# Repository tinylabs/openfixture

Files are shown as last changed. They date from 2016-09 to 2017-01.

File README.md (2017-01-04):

# OpenFixture





## Goal
The motivation of OpenFixture was to make a parametric fixturing system that could take fully generated inputs from kicad and produce a test fixture with minimal effort. The easiest way to use it is through the kicad python scripting interface.

## Parameters
For most projects (if using the standard BOM) the only parameters you'll need to set are mat_th and pcb_th. Something like the following should be sufficient:
```
./GenFixture.py --board [path to board.kicad_pcb] --mat_th [thickness in mm] --pcb_th [thickness in mm] --out board-fixture

usage: GenFixture.py [-h] --board BOARD --mat_th MAT_TH --out OUT
                     [--pcb_th PCB_TH] [--screw_len SCREW_LEN]
                     [--screw_d SCREW_D] [--layer LAYER] [--flayer FLAYER]
                     [--ilayer ILAYER]

optional arguments:
  -h, --help            show this help message and exit
  --board BOARD         <board_name.kicad_pcb>
  --mat_th MAT_TH       material thickness (mm)
  --out OUT             output directory
  --pcb_th PCB_TH       pcb thickness (mm)
  --screw_len SCREW_LEN  Assembly screw thread length (default = 14mm)
  --screw_d SCREW_D     Assembly screw diameter (default=M3)
  --layer LAYER         F.Cu | B.Cu
  --flayer FLAYER       Eco1.User | Eco2.User
  --ilayer ILAYER       Eco1.User | Eco2.User
```					    
The resulting output is:
  * A 3D model of the test fixture for visualization
  * A 2D DXF that can be directly lasercut for assembly

## Recommended workflow for kicad
  1. Clone this repo if you haven't already
  2. Setup a project specific bash script (use genfixture.sh as an example)
  3. Enter board specific info, fixture hardware, material thickness, etc.
  4. Whenever the layout changes call ./genfixture.sh (from repo) and pass path to .kicad_pcb file.
  5. Fixture will be generated in $OUTPUT folder.
  6. If anyone is interested in integrating this into kicad directly I'd be happy to support it and clean it up...
  
## Hardware
  * All that is needed is M3 (14mm+) screws, M3 hex nuts, and lasercut parts
  * I use nylon bushings in the main pivot with m3 screws for a smoother joint but this is optional 

## Documentation
http://tinylabs.io/openfixture

## BOM
http://tinylabs.io/openfixture-bom

## Kicad export
http://tinylabs.io/openfixture-kicad-export

## Assembly
More info including detailed assembly instructions at http://tinylabs.io/openfixture-assembly

## Dependencies
  * Newer version of openscad >= 2015.03-1
  * kicad or other EDA software. Please email me if you have instructions for other packages so I can add them.

## Known Issues
  * When loading the fonts file a new small window opens in Ubuntu. Seems innocuous but still annoying [Only seen on ubuntu 14.04]

## License
Creative Commons (CC BY-SA 4.0)

## Contributors
  * Elliot Buller - Tiny Labs Inc

Please email with any pull requests or new feature requests
elliot@tinylabs.io

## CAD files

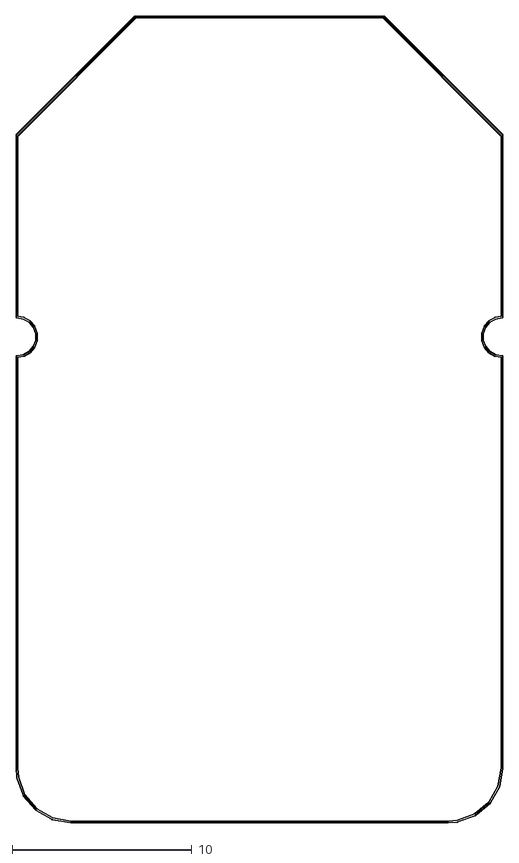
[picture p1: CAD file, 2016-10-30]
rfid_fob-outline.dxf
27.1 x 44.9

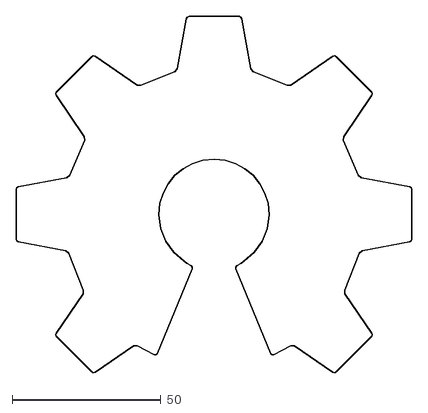
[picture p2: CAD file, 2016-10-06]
osh_logo.dxf
132.9 x 119.6

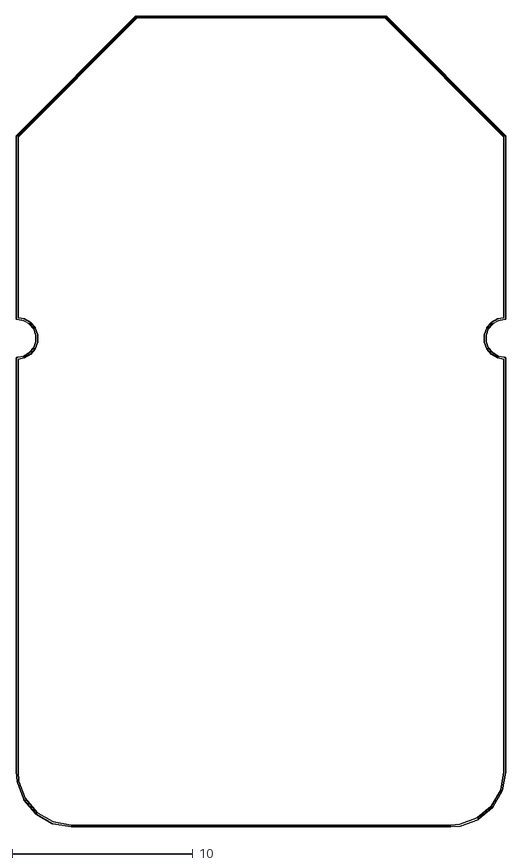
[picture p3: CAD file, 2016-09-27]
keysy_outline.dxf
27.1 x 44.9

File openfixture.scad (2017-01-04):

/**
 *  OpenFixture - The goal is to have a turnkey pcb fixturing solution
 *  as long as you have access to a laser cutter or laser cutting service.
 *
 *  The input is:
 *   1. (x, y) work area that is >= pcb size
 *   2. (x, y) cooridates of test point centers
 *   3. dxf of pcb outline aligned with (0,0) on the top left.
 *   4. Material parameters: acrylic thickness, kerf, etc
 *
 *  The output is a dxf containing all the parts (minus M3 hardware)
 *  to assemble the fixture.
 *
 *  Creative Commons Licensed  (CC BY-SA 4.0)
 *  Tiny Labs
 *  2016
 */
use <glaser-stencil-d.ttf>
FONTNAME = "Glaser Stencil D";

//
// PCB input
//
// Test points
test_points = [[23.22,25.85],[19.72,22.28],[3.95,25.77],[7.52,22.27],[13.60,13.70],[13.55,18.70],[13.55,34.90],[13.60,29.90],];

// Used below to calculate distance from hinge to nearest point based on min
// contact angle... Ideally we want it as close to 90 degrees as possible
// All you have to know is look through 'y' column above and set to lowest val
tp_min_y = 13.7;

// DXF outline of pcb
pcb_outline = "./rfid_fob-outline.dxf";
osh_logo = "./osh_logo.dxf";

// PCB revision
rev = "rev.0";

// Should be close to actual pcb dimensions... Used for support structure only so not critical
pcb_x = 27.14;
pcb_y = 45;
pcb_support_border = 2;

// Work area of PCB
// Must be >= PCB size
// If you make this as big as any of the PCBs you work 
// with you could then reuse the base and just swap the
// head and carriers based on the pcb you're using. 
work_area_x = pcb_x;
work_area_y = pcb_y;

// Thickness of pcb
pcb_th = 1.6;  // Standard PCB size

//
// End PCB input
//

// Correction offset
// These are final adjustments relative to the board carrier.
// Usually these aren't needed but can be used to tweak alignment
tp_correction_offset_x = 0.0;
tp_correction_offset_y = 0.0;

// Uncomment for alignment check, can be a quick sanity check to
// make sure everything lines up.
//projection (cut = false) alignment_check ();
mode = "3dmodel";
//mode = "lasercut";
//mode = "validate";
//mode = "testcut";
//mode = "none";

// Uncomment for laser cuttable dxf
if (mode == "lasercut") projection (cut = false) lasercut ();
if (mode == "3dmodel") 3d_model ();
if (mode == "validate") validate_testpoints (pcb_outline);
if (mode == "testcut") projection (cut = false) testcut ();

// Smothness function for circles
$fn = 15;

// All measurements in mm
// Material parameters
mat_th = 3.0;

// Kerf adjustment
kerf = 0.125;

// Space between laser parts
laser_pad = 2;

// Screw radius (we want this tight to avoid play)
// This should work for M3 hardware
// Just the threads, not including head
// Should be no less than 12
screw_thr_len = 16;
screw_d = 3.0;
screw_r = screw_d / 2;

// Uncomment to use normal M3 screw for pivot
// We need pivot_d tight for precise alignment
pivot_d = screw_d - 0.1;
// Uncomment to use bushing in pivot
//pivot_d = 5.12;
pivot_r = pivot_d / 2;

// Pivot support, 3mm on either side 
pivot_support_d = pivot_d + 6;
pivot_support_r = pivot_support_d / 2;

// Metric M3 hex nut dimensions
// f2f = flat to flat
nut_od_f2f = 5.45;
nut_od_c2c = 6;
nut_th = 2.25;

// Option to add nylon washer on latching mechanism for smoother
// operation - disabled by default
washer_th = 0;
//washer_th = 1;

// Pogo pin receptable dimensions
// I use the 2 part pogos with replaceable pins. Its a lifer save when a 
// pin breaks. Undersized so they can be carefully drilled out using #50
// drill bit for better precision. If you have access to a nicer laser you 
// can size these exactly
pogo_r = 1.5 / 2;

// Uncompressed length from receptacle
pogo_uncompressed_length = 8;
pogo_compression = 1;

// Locking tab parameters
tab_width = 3 * mat_th;
tab_length = 4 * mat_th + washer_th;

// Stop tab
stop_tab_y = 2 * mat_th;

//
// DO NOT EDIT BELOW... unless you feel like it ;-)
//
// Calculate min distance to hinge with a constraint on
// the angle of the pogo pin when it meets compression with the board.
// a = compression
// c = active_y_offset + pivot_support_r
// cos (min_angle) = a^2 / (2ca)
min_angle = 89.5;

// Calculate active_y_back_offset
active_y_back_offset = (pow (pogo_compression, 2) / (cos (min_angle) * 2 * pogo_compression)) - pivot_support_r - tp_min_y;

// Active area parameters
active_x_offset = 2 * mat_th + nut_od_f2f + 2;
active_y_offset = 2 * mat_th + nut_od_f2f + 2;

// Head dimensions
head_x = work_area_x + 2 * active_x_offset;
head_y = work_area_y + active_y_offset + active_y_back_offset;
head_z = screw_thr_len - nut_th;

// Base dimensions
base_x = head_x + 2 * mat_th;
base_y = head_y + pivot_support_d;
base_z = screw_thr_len + 3 * mat_th;
base_pivot_offset = pivot_support_r + 
                    (pogo_uncompressed_length - pogo_compression) -
                    (mat_th - pcb_th);

// To account for capture nut overhang
nut_pad = (nut_od_c2c - mat_th) / 2;

// Derived latch dimensions
latch_z_offset = (base_z * (2 / 3) + base_pivot_offset - pivot_r) / 2;
support_x = base_x / 12 + 2 * mat_th;
latch_support_y = base_z * (2 / 3) + base_pivot_offset - pivot_support_r - 2 * mat_th;
//
// MODULES
//
module tnut_female (n, length = screw_thr_len)
{
    // How much grip material
    tnut_grip = 4;
    
    // Pad for screw
    pad = 0.4;
    screw_len_pad = 1;
    
    // Screw hole
    translate ([0, -screw_r - pad/2, 0])
    cube ([length + screw_len_pad, screw_d + pad, mat_th]);
    
    // Make space for nut
    translate ([mat_th * n + tnut_grip, -nut_od_f2f/2, 0])
    cube ([nut_th, nut_od_f2f, mat_th]);
}

module tnut_hole ()
{
    pad = 0.1;
    cylinder (r = screw_r + pad, h = mat_th, $fn = 20);
}

module tng_n (length, cnt)
{
    tng_y = (length / cnt);
    
    translate ([0, -length / 2, 0])
    union () {
        for (i = [0 : 2 : cnt - 1]) {
            translate ([0, i * tng_y, 0])
            cube ([mat_th, tng_y, mat_th]);
        }
    }
}

module tng_p (length, cnt)
{
    tng_y = length / cnt;
    
    translate ([0, -length / 2, 0])
    union () {
        for (i = [1 : 2 : cnt - 1]) {
            translate ([0, i * tng_y, 0])
            cube ([mat_th, tng_y, mat_th]);
        }
    }
}

module nut_hole ()
{
    pad = 0.05;
    cylinder (r = nut_od_c2c/2 + pad, h = mat_th, $fn = 6);
}

module testcut ()
{
    y = 30;
    off = 3 * mat_th + laser_pad;
    
    difference () {
        union () {
            cube ([3 * mat_th, y, mat_th]);
        
            translate ([off, 0, 0])
            cube ([screw_thr_len + 2 * mat_th, y - 2 * mat_th, mat_th]);
        }
        // Remove tng slot
        translate ([mat_th, y/2, 0])
        tng_n (y - 2 * mat_th, 3);
        
        // Remove tnut hole
        translate ([mat_th * 3/2, y/2, 0])
        tnut_hole ();
        
        // Remove tng from male side
        translate ([off, y/2 - mat_th, 0])
        tng_p (y - 2 * mat_th, 3); 
        
        // Remove tnut
        translate ([off, y/2 - mat_th, 0])
        tnut_female (1);
        
        // Remove nut hole
        translate ([off + nut_od_c2c / 2 + screw_thr_len - mat_th, nut_od_f2f / 2 + 2, 0])
        nut_hole ();
    }
}

module head_side ()
{
    x = head_z;
    y = head_y;
    r = pivot_support_r;
    
    difference () {
        union () {
            hull () {
                translate ([0, y, 0])
                cube ([x, 0.01, mat_th]);
                
                // Add pivot point
                translate ([r, y + pivot_support_r, 0])
                cylinder (r = pivot_support_r, h = mat_th, $fn = 20);
            }
            cube ([x, y, mat_th]);
        }
            
        // Remove pivot
        translate ([r, y + r, 0])
        cylinder (r = pivot_r, h = mat_th, $fn = 20);
        
        // Remove slots
        translate ([0, y / 2, 0])
        tng_n (y, 3);
        translate ([x - mat_th, y / 2, 0])
        tng_n (y, 3);
        
        // Remove lincoln log slots
        translate ([0, mat_th, 0])
        cube ([x / 2, mat_th, mat_th]);
        translate ([0, y - 3 * mat_th, 0])
        cube ([x / 2, mat_th, mat_th]);
    }
}

module head_front_back ()
{
    x = head_x;
    y = head_z;
    
    difference () {
        cube ([x, y, mat_th]);
        
        // Remove grooves
        translate ([x / 2, 0, 0])
        rotate ([0, 0, 90])
        tng_n (x, 3);
        translate ([x / 2, y - mat_th, 0])
        rotate ([0, 0, 90])
        tng_n (x, 3);
        
        // Remove assembly slots
        translate ([mat_th, y / 2, 0])
        cube ([mat_th, y / 2, mat_th]);
        translate ([x - 2 * mat_th, y / 2, 0])
        cube ([mat_th, y / 2, mat_th]);
    }
}

module lock_tab ()
{
    translate ([-tab_length/2, 0, 0])
    cube ([tab_length, tab_width, mat_th]);
    translate ([-tab_length/2, tab_width/2, 0])
    cylinder (r = tab_width / 2, h = mat_th, $fn = 20);
}
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

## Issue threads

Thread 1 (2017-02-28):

Documentation unclear/outdated

kasbah, 2017-02-28:
Hey, thanks very much for this. I am considering using it for a testing a small batch of assemblies.

I am a bit confused about the docs. Is http://tinylabs.io/openfixture-config/ outdated? How do I set my test-points now?

ebuller, 2017-02-28:
Hi kasbah,

Yes, that is out of date but still an option. The easiest way (if you're using kicad) is to use the GenFixture.py python wrapper that will extract the test points and the DXF outline. The README file has more information. genfixture.sh is an example of how to call GenFixture.py. Let me know if you get stuck.

ebuller, 2017-02-28:
If you find bugs (which I'm sure there may be many) please let me know or submit a patch.

kasbah, 2017-02-28:
It actually works really well! I don't have SMD test-points just through hole ones and I don't care about what layer they are on which was confusing it and me so I had to modify the function a bit.

OT: Just stumbled upon the Keysy. Looks really interesting! If I pre-order now what are the delivery estimates? Are you planning to open source any of it (firmware, hardware)?

ebuller, 2017-02-28:
The way it's currently setup you can edit any pad (in kicad) and add it to User.Eco2 layer. This will force a test point to get generated when running the script. If you have any SMD pads with no paste layer you can add them to User.Eco1 to force the script to ignore them and not generate a test point.

Thanks! Keysy is a little behind schedule. It's looking like it will be a couple months until we ship. I'd love to open source the firmware but I've spent the last couple years on the project without pay so quite frankly I can't afford to...

kasbah, 2017-03-17:
Still trying to see if I can use this for our Kickstarter batch of the [VRGO Chair](http://vrgochair.com). Not sure if this is me being stupid again but from the instructions it seems like these bits should have been generated as hex nut cut-outs?

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

ebuller, 2017-03-17:
They were but they didn't need to be so I changed it. Due to the length of
the pogos the top doesn't sit flush so that wasn't necessary. These
clearance holes prevent you from having to glue the nuts in.

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

brainstorm, 2017-08-31:
@ebuller I am a bit stuck myself with KiCad python scripting and your `genfixture.sh`. I've posted some details over an [official kicad forum thread](https://forum.kicad.info/t/make-python-lib-pcbnew-global-on-mac/4017/5). If you could provide some guidance over here or there in the forum, it would be greatly appreciated.

I look forward to build my own board's fixture with your software, excellent work 👍

ebuller, 2017-08-31:
Hi Roman,

I just cloned the latest and tried on my system (Ubuntu 14.04.5 LTS). Can
you try the same and let me know what the output is?

elliot@elliot-macmini:~/projects$ git clone
https://github.com/ebuller/openfixture.git openfixture-staging
Cloning into 'openfixture-staging'...
remote: Counting objects: 132, done.
remote: Total 132 (delta 0), reused 0 (delta 0), pack-reused 132
Receiving objects: 100% (132/132), 352.21 KiB | 0 bytes/s, done.
Resolving deltas: 100% (63/63), done.
Checking connectivity... done.
elliot@elliot-macmini:~/projects$ cd openfixture-staging/
elliot@elliot-macmini:~/projects/openfixture-staging$ ./genfixture.sh
../keysy/hw/pcba/keyfob/kicad/keysy_keyfob.kicad_pcb
16:16:51: Debug: Skipping general section token 'links'
16:16:51: Debug: Skipping general section token 'area'
16:16:51: Debug: Skipping general section token 'drawings'
16:16:51: Debug: Skipping general section token 'tracks'
16:16:51: Debug: Skipping general section token 'zones'
16:16:51: Debug: Skipping general section token 'symbol'
Generating Fixture...
Fixture generated:
/home/elliot/projects/openfixture-staging/fixture-v10/keysy_keyfob-fixture.dxf

Thanks,
Elliot

On Thu, Aug 31, 2017 at 4:04 PM, Roman Valls Guimerà <
notifications@github.com> wrote:

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

--
Founder
Tiny Labs - Small Space Big Ideas
http://tinylabs.io

<http://goo.gl/NDg6WB>

brainstorm, 2017-08-31:
Sure and thanks for the fast reply! Please keep in mind I'm running on OSX Sierra 10.12.6 with KiCAD nightly from 2017-08-21:

```
brainstorm:openfixture romanvg$ ls
GenFixture.py        README.md            glaser-stencil-d.ttf openfixture.scad     rfid_fob-outline.dxf
GenFixture.pyc       genfixture.sh        ohw_logo.svg         osh_logo.dxf
brainstorm:openfixture romanvg$ ./genfixture.sh
Traceback (most recent call last):
  File "GenFixture.py", line 26, in <module>
    from pcbnew import *
ImportError: No module named 'pcbnew'
brainstorm:openfixture romanvg$ ./genfixture.sh ~/dev/espDonut/hardware/esp_donut.kicad_pcb
Traceback (most recent call last):
  File "GenFixture.py", line 26, in <module>
    from pcbnew import *
ImportError: No module named 'pcbnew'
```

ebuller, 2017-08-31:
Yeah unfortunately I don't have OSX to test on. It's definitely not finding
the python scripting library... Try this:
1. Open Pcbnew GUI from kicad normally.
2. Click Tools->Scripting Console
3. Type the following:
>>> import pcbnew
>>> print pcbnew.__file__
/usr/lib/python2.7/dist-packages/pcbnew.py
>>>

Let me know the output.
Thanks,
Elliot

On Thu, Aug 31, 2017 at 4:33 PM, Roman Valls Guimerà <
notifications@github.com> wrote:

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

--
Founder
Tiny Labs - Small Space Big Ideas
http://tinylabs.io

<http://goo.gl/NDg6WB>

brainstorm, 2017-09-01:
```
Py 0.9.8
Python 2.7.10 (default, Feb  7 2017, 00:08:15)
[GCC 4.2.1 Compatible Apple LLVM 8.0.0 (clang-800.0.34)] on darwin
Type "help", "copyright", "credits" or "license" for more information.
Startup script executed: /Users/romanvg/Library/Preferences/kicad/PyShell_pcbnew_startup.py
>>> import pcbnew
>>> print pcbnew.__file__
/Applications/Kicad/kicad.app/Contents/Frameworks/python/site-packages/pcbnew.pyc
>>>
```

brainstorm, 2017-09-01:
After a bit of library hacks to resolve the `Reason: image not found` from `dlopen`-ing the `_pcbnew.so` shared lib:

```
$ cat fix_osx_pcbnew_kicad_libs.sh
#!/bin/bash
# Inspired on: https://www.bountysource.com/issues/31269729-libwx_osx_cocoau-3-1-dylib-not-found

KICAD_LIBS_TOFIX="libwx_osx_cocoau_gl-3.0.0 libwx_osx_cocoau_adv-3.0.0 libwx_osx_cocoau_aui-3.0.0 libwx_osx_cocoau_adv-3.0.0 libwx_osx_cocoau_html-3.0.0 libwx_osx_cocoau_core-3.0.0 libwx_osx_cocoau_stc-3.0.0 libkicad_3dsg.2.0.0 libGLEW.2.0.0 libcairo.2 libpixman-1.0 libwx_baseu_net-3.0.0 libwx_baseu-3.0.0 libwx_baseu_xml-3.0.0"

#KICAD_LIBS_TOFIX=`find /Applications/Kicad/kicad.app/Contents/Frameworks/ -iname *.dylib | xargs otool -L | grep executable_path | awk '{print $1}' | awk -F'/' '{print $4}'`

for kicadlib in $KICAD_LIBS_TOFIX;
do
	echo "Fixing ${kicadlib} broken path on pcbnew..."
	install_name_tool -change @executable_path/../Frameworks/${kicadlib}.dylib /Applications/Kicad/kicad.app/Contents/Frameworks/${kicadlib}.dylib /Applications/Kicad/pcbnew.app/Contents/Frameworks/python/site-packages/_pcbnew.so
done

echo "Done! All paths should be absolute now, no @executable_path in:"
otool -L /Applications/Kicad/kicad.app/Contents/Frameworks/python/site-packages/_pcbnew.so
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
brainstorm, 2017-09-01:
After a bit more fiddling I succeded!:

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

I'll put together the changes below a bit better in a proper pullrequest later on, but wanted to share this so that others can use it ;)

```
diff --git a/GenFixture.py b/GenFixture.py
index 670580c..f8296ff 100755
--- a/GenFixture.py
+++ b/GenFixture.py
@@ -1,4 +1,4 @@
-#!/usr/bin/python
+#!/Applications/Kicad/pcbnew.app/Contents/MacOS/Python
 #
 # Kicad OpenFixture Generator
 #
@@ -20,6 +20,9 @@
 import os
 import sys
 import argparse
+
+sys.path.insert(0, "/Applications/Kicad/kicad.app/Contents/Frameworks/python/site-packages")
+
 from pcbnew import *

 # Defaults
@@ -149,7 +152,7 @@ class GenFixture:
         popt.SetSubtractMaskFromSilk(False)

         # Do the BRD edges in black
-        popt.SetColor(BLACK)
+        popt.SetColor(COLOR4D.BLACK)

         # Open file
         pctl.SetLayer(Edge_Cuts)
@@ -181,7 +184,7 @@ class GenFixture:
             if self.rev == "":
                 self.rev = "rev.0"

-        # Call openscad to generate fixture
+        # Call /Applications/OpenSCAD.app/Contents/MacOS/OpenSCAD to generate fixture
         args = "-D\'test_points=%s\'" % self.GetTestPointStr ()
         args += " -D\'tp_min_y=%.02f\'" % self.min_y
         args += " -D\'mat_th=%.02f\'" % self.mat_th
@@ -214,19 +217,19 @@ class GenFixture:
         testout= path + "/" + self.prj_name + "-test.dxf"

         # This will take a while, print something
-        print "Generating Fixture..."
+        print("Generating Fixture...")

         # Create test part
-        os.system ("openscad %s -D\'mode=\"testcut\"\' -o %s openfixture.scad" % (args, testout))
+        os.system ("/Applications/OpenSCAD.app/Contents/MacOS/OpenSCAD %s -D\'mode=\"testcut\"\' -o %s openfixture.scad" % (args, testout))

         # Create rendering
-        os.system ("openscad %s -D\'mode=\"3dmodel\"\' --render -o %s openfixture.scad" % (args, pngout))
+        os.system ("/Applications/OpenSCAD.app/Contents/MacOS/OpenSCAD %s -D\'mode=\"3dmodel\"\' --render -o %s openfixture.scad" % (args, pngout))

         # Create laser cuttable fixture
-        os.system ("openscad %s -D\'mode=\"lasercut\"\' -o %s openfixture.scad" % (args, dxfout))
+        os.system ("/Applications/OpenSCAD.app/Contents/MacOS/OpenSCAD %s -D\'mode=\"lasercut\"\' -o %s openfixture.scad" % (args, dxfout))

         # Print output
-        print "Fixture generated: %s" % dxfout
+        print("Fixture generated: %s".format(dxfout))

     def GetTestPointStr (self):
         tps = "["
@@ -252,7 +255,7 @@ class GenFixture:
                     #else check ignore cases
                     elif ((p.IsOnLayer (self.ignore_layer) == True) or
                           (p.IsOnLayer (self.paste) == True) or
-                          (p.GetAttribute () != PAD_SMD)):
+                          (p.GetAttribute () != D_PAD_SMDMask())):
                         continue

                     # Print position
```

ebuller, 2017-09-01:
Awesome! Glad you figured it out. Some of the changes look specific to OSX
but I'll try and pick up the portable changes. Good info though for anyone
on OSX...

On Fri, Sep 1, 2017 at 9:11 AM, Roman Valls Guimerà <
notifications@github.com> wrote:

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

--
Founder
Tiny Labs - Small Space Big Ideas
http://tinylabs.io

<http://goo.gl/NDg6WB>

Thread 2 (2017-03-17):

Does the 'kerf' variable actually get used?

robot-army, 2017-03-17:
It doesn't seem so, should I just adjust material thickness with a fudge factor?

ebuller, 2017-03-17:
Hi Ryan,
Yeah I need to remove that, I don't believe it's used anymore. I measure my
material with calipers in a few places and use the largest for material
thickness. Your mileage may vary depending on your laser though.

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

robot-army, 2017-03-17:
My material thickness is pretty consistent, but getting tight fits where there's finger joints requires some adjustment of that parameter to account for laser kerf right?

ebuller, 2017-03-17:
I see, the laser I have access to is shared and pretty well abused so the
kerf probably adds enough slop. Let me know what u come up with and I'll
pull it back in if others can use it.

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

MrSurly, 2017-12-12:
FWIW, laser-cut from Ponoko fits pretty tightly, but I had to file out the board carrier to get my boards to fit without binding.  Maybe a parameter for board fit in the carrier?

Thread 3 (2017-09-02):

Ponoko blue fixture lines

brainstorm, 2017-09-02:
@ebuller I'm trying to ship the fixture through Ponoko but I'm hitting an issue with the laser cut color coding:

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

Apparently [their design rules expect Blue lines for laser cuts](https://ponoko.zendesk.com/hc/en-us/community/posts/210090388-File-won-t-upload-and-says-Oops-Please-Check-Your-Stroke-Colors-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) and Red ones for engraving... I just need laser cuts (blue lines) in the DXF.

I tried to modify `GenFixture.py` script this way (instead of the default BLACK), here are my attemps, commented:

```
        # popt.SetColor(COLOR4D.BLACK)
        #
        # BLUE in https://github.com/KiCad/kicad-source-mirror/blob/d7bf44eee0a1ac4cf9a852d66c4ed65fff9cb788/include/colors.h
        # According to https://forum.kicad.info/t/plot-scripting-api-color-choice-for-layers/2074/4
        # popt.SetColor(COLOR4D(12))
        popt.SetColor(COLOR4D(0, 0, 255, 0))
```

With no success so far, the fixtures remain black...

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

Do you know an easier way to specify blue lines by default? Perhaps in the scad file directly?

Thanks in advance!

ebuller, 2017-09-02:
Hi Roman,

I tried doing the same thing originally and couldn't get it to work... Now
when going through ponoko I download their template for inkscape (SVG).
Import the DXF, change the stroke and color and resave as SVG. Let me know
if you get stuck anywhere. Inkscape is free and open source, there should
be an OSX version. Any program that can handle vector files should work
though.

Thanks,
Elliot

On Fri, Sep 1, 2017 at 5:19 PM, Roman Valls Guimerà <
notifications@github.com> wrote:

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

--
Founder
Tiny Labs - Small Space Big Ideas
http://tinylabs.io

<http://goo.gl/NDg6WB>

brainstorm, 2017-09-02:
Yes, that's exactly what I ended up doing 10 minutes afterwards and it worked, but of course it would great to have it all automated, sad/glad to see I'm not alone 👍

Closed 2017-09-02.

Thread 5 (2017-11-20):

Fixture output seems to believe my board has a very small y dimension

MrSurly, 2017-11-20:
Attached the resultant files.

The X appears correct (board is approximately 100mm), but the y dimension of the resultant fixture is close to zero.

Can provide source kicad_pcb file privately.

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
[x.zip](https://github.com/ebuller/openfixture/files/1486667/x.zip)

MrSurly, 2017-11-22:
Figured it out.  Was set for bottom copper,where there are no pads.

Closed 2017-11-22.

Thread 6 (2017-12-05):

Are you accepting PRs?

MrSurly, 2017-12-05:
I'm doing active development on this, in a fork.  Would PRs be accepted?

* Modified locking tabs to be more robust
* Made 2d rendering very fast
* 3d rendering optional (but still faster than it was)
* Adding an option to rotate the PCB before generating the fixture

ebuller, 2017-12-06:
 Hi Eric,

Definitely interested in pull requests. It's been more or less unmaintained
while I've been stuck on other projects. I'd like to clean it up and
integrate your changes but I won't have the cycles until January. I'd also
like to integrate it as a plugin to Pcbnew to make it easier for other
people to use it.

Appreciate the help!
-Elliot

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

MrSurly, 2017-12-07:
I'm also swamped.  All my changes are committed to master; I'll break them out logically, with separate PRs for each, when time allows.

I never did get the "rotate PCB" option to work; the `pcbnew.Board` object does indeed have a `Rotate` method, but it segfaults somwhere in WxWindows when used.

MrSurly, 2017-12-12:
Submitting several PRs today.

I have a combined version, if desired.

ebuller, 2017-12-13:
Thanks Eric, looks good. In China right now for work but once I get back
I'll integrate those in.

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

Closed 2017-12-13.

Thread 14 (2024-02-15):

Compatibility with Kicad 6

elkingonzalo, 2024-02-15:
I have tried to use OpenFixture and it seems that procedure to export from Kicad to DXF now is not compatible according to the indications given in OpenFixture documentation. [https://tinylabs.io/openfixture-kicad-export/]

This is the available options in the last Kicad available version
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

It seems that the needed option "use auxiliary axis as origin" now is **not available anymore** in Kicad.

Then is not possible to proceed according to the procedure.

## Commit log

2016-09-28 Fix DXF spacing for latch, set screw size as default pivot.
    [openfixture.scad]
2016-10-05 Add openhardware svg logo to incorporate into top plate
2016-10-06 Fixed a couple bugs, flipped lower head plate to allow assembly without glue.
    [openfixture.scad, osh_logo.dxf]
2016-10-12 Update variables to match web guide
    [openfixture.scad]
2016-10-12 Add back support for main hinge
    [openfixture.scad]
2016-10-12 Update laserable dxf to use new back support
    [openfixture.scad]
2016-10-29 Update python script and scad generator
    [openfixture.scad]
2016-10-29 Change font, fix front support in lasercut, add revision
    [openfixture.scad]
2016-10-29 Rearrange lasercut layout
    [openfixture.scad]
2016-10-30 Fix weak geometry, update README
    [openfixture.scad, rfid_fob-outline.dxf]
2016-10-30 Remove stop tab, add cutout on head base to allow full swivel
    [openfixture.scad]
2016-11-11 Add washer option and linear lasercut layout
    [openfixture.scad]
2016-11-12 Add optional args to python, gen 3d rendering + testcut for fit
    [openfixture.scad]
2016-11-13 Fix back top head holes that don't line up (oops)
    [openfixture.scad]
2016-12-23 Tighten pivot_d for precision, increase back base height for strength
    [openfixture.scad]
2017-01-04 Change hex holes to normal clearance holes, add cable management
    [openfixture.scad]
